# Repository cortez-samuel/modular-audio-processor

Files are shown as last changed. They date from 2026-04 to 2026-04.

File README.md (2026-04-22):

# Modular Audio Processor (Production Release)

## Overview
A real-time audio effects processor built on the Adafruit Feather RP2040. It processes I2S digital audio through various filters (Low-pass, High-pass, Gain, Quantize) and provides a live waveform/FFT visualization on an SSD1306 OLED display.

## Architecture
The system utilizes a multi-core architecture to ensure real-time audio processing performance.

- **Core 0 (Real-time Audio):**
    - Manages I2S Rx/Tx PIO state machines and DMA channels (`I2S.cpp`, `TxPingPong.cpp`).
    - Processes audio samples using floating-point filters (`filters.cpp`).
    - Maintains cyclic buffers for filter history (`CyclicBuffer_t`).
- **Core 1 (UI & Control):**
    - Renders the OLED display (`oled.cpp`), switching between Waveform and FFT views.
    - Handles user input via rotary encoders and push buttons (`RotaryEncoder.hpp`, `PushButton.hpp`).
    - Manages non-volatile storage of settings in flash memory.
- **Inter-Core Communication:**
    - A FIFO queue (`sharedQueue`) passes downsampled audio data from Core 0 to Core 1 for visualization without locking.

## Features
- **Audio Effects:**
    - **SRC:** Pass-through
    - **LPF/HPF:** First-order IIR filters with adjustable cutoff (`alpha`)
    - **GAIN:** Quadratic gain scaling
    - **QTZ:** Bit-crusher/Quantizer effect
- **Visualization:**
    - Real-time Oscilloscope
    - Real-time FFT Spectrum Visualizer (256 bins)
- **Persistence:** Saves current Mode and Alpha value to flash memory. It automatically restores on next power-up.

## Hardware Components
- Microcontroller: Adafruit Feather RP2040
- Display: SSD1306 OLED (128x64)
- Audio Codec: PCM5102 DAC Decoder Module and Mini Loudspeaker (3 Watt, 4 Ohm)
- Input: 2x CYT1100 Rotary Encoders with Push Switch

## Pinout
| Component | Pin Function | GPIO Pin |
|---|---|---|
| **OLED Display**| SCK | 10 |
| | MOSI (TX) | 11 |
| | RST | 28 |
| | DC | 29 |
| | CS | 24 |
| **I2S Audio** | Tx Data | 0 |
| | Tx BCLK | 2 |
| | Tx WS (LRCLK)| 3 |
| | Rx Data | 7 |
| | Rx BCLK | 8 |
| | Rx WS (LRCLK)| 9 |
| **Controls** | Mode Enc A | 12 |
| | Mode Enc B | 13 |
| | Mode SW | 25 |
| | Alpha Enc A  | 1 |
| | Alpha Enc B  | 6 |
| | Alpha SW | 20 |

## Build Instructions
1. Install the Raspberry Pi Pico SDK
2. Clone this repository
3. Create a `build` directory: `mkdir build && cd build`
4. Run CMake: `cmake ..`
5. Compile: `make`
6. Flash the `.uf2` file to the RP2040

## Usage
- **Mode Selection:** Turn the *Left* encoder to cycle between effects (SRC, LPF, HPF, GAIN, QTZ, FFT). Press the *Left* encoder button to reset to SRC mode.
- **Parameter Adjustment:** Turn the *Right* encoder to adjust the filter parameter (`alpha`). Press the *Right* encoder button to reset the parameter to `1.00` (or max).
- **Visualization:** The display will automatically show the waveform or FFT based on the selected mode.
- **Saving:** Settings are saved automatically after the last change.

## Known Bugs
- When continuously changing the alpha value when there is an incoming signal, both the display and audio output pause very briefly. This is because saving the flash memory operates within an ISR, which briefly stops the rest of the program to complete the flash write. We were not able to implement a solution to this as the ISR is needed to prevent reading and writing at the same time, which caused the system to crash during testing.

---

# Modular Audio Processor (Release Candidate)

## Overview
In the Release Candidate version of the Modular Audio Processor, the system consists of a dedicated input and one or more functions that connect via POGO pins. The system supports real-time DSP filtering and live FFT visualization, with all settings capable of being stored in flash memory. The Release Candidate represents a mostly polished build, as all planned features are integrated, the casings are complete, and usability has been refined based on feedback from our beta testing phase.

## Completed Work

### Hardware and Physical Design
- Designed and constructed dedicated input and function module casings (3D-printed and assembled).
- Input Module now uses a 3.5mm headphone jack for analog audio input instead of the DAD board's Waveform Generator.
- Function Modules output processed audio through a dedicated DAC with a 3.5mm headphone jack.
- System power is supplied using a USB-C breakout board (no direct connection to RP2040 USB-C port).
- User controls now use a rotary encoder instead of a potentiometer for intuitive control. Turning it adjusts the filter parameter alpha and pressing it changes the current DSP mode.
- Another button was added to allow the user to save these settings to flash memory, allowing the configuration to persist even after the system loses power.

### Intermodular Communication
- Full I2S-based communication using the RP2040 PIO for stereo-aligned, low-latency audio at 44.1 kHz
- We're still using dual-core optimization, with Core 0 handling the real-time audio pipeline (I2S RX -> DSP -> I2S TX) and Core 1 handling the OLED display logic.
- Added clock-forward PIO program to maintain clean BCLK/WS synchronization across chained modules.

### DSP Features
- The system now uses fixed-point arithmetic throughout for low latency and highly precise processing.
- Downsampled waveform/FFT data streamed to the display without impacting audio performance.

## Project Architecture

### Module Types
- **Input Module**: Reads analog audio from the 3.5mm headphone jack via the RP2040 ADC, performs fixed-point conversion, and transmits stereo I2S audio at 44.1 kHz frequency over POGO pins.
- **Function Module**: Receives I2S audio via POGO pins, applies the selected filter or FFT, and forwards the processed audio via I2S TX. It also handles user input (rotary encoder + mode button), flash persistence, and OLED display.

### Core Allocation
- **Core 0** (audio/DSP): I2S RX -> selectable filter or FFT -> I2S Tx. Uses DMA ping-pong buffers for zero-copy, real-time operation. It includes downsampling for display data.
- **Core 1** (OLED Display): Drives the 128 by 64 SSD1306 OLED display, renders either a live oscilloscope-style waveform display or FFT bar graph, and displays current mode and alpha value.

### State & Persistence
- Mode and alpha are stored in the last flash sector using a magic-byte header.
- `loadMode()` and `saveMode()` run at boot and on every user change.
- Flash writes are performed safely with `flash_safe_execute` to avoid XIP conflicts.

### Inter-Module Communication
- I2S bus (BCLK, WS, SD) carried over POGO pins.
- Dedicated PIO program forwards the clock signals to maintain synchronization in long chains.
- Power and ground are also passed through the POGO connectors.

## Known Bugs
- If the user partially disconnects the modules in such a manner that the POGO pins transmitting the I2S signals are detached but VCC and GND are stil connected, once the user fully reconnects the modules, it messes up the audio signal. This is caused by the PIO using autopull. However, this would be something that the user would need to delibrately do and isn't an issue that would usually come up in normal use.
- There are rare DMA underflow events that print a debug message to UART during extreme buffer starvation (though this is never audible in normal use and is automatically recovered by inserting default data).
- In this version, there are no major bugs, crashes, or loss of functionality. The edge cases (power-cycle, rapidly changing modes, alpha = 0, and buffer overflow/underflow) are handled properly.

---

# Modular Audio Processor (Beta Build)

## Completed Work
During the beta building phase, we primarily focused on transitioning from our breadboard prototype to a robust, integrated hardware system and improving the intermodular communication.

### Hardware and Physical Design
- Designed and implemented the first iteration of 3D-printed casings and moved away from prototyping breadboards.
- Replaced breadboard wiring with magnetic pogo pins for connection between modules
- Most internal components have been successfully fitted into their respective module casings.

### Firmware and Intermodular Communication
- Switched from SPI to I2S protocol using the RP2040's PIO to ensure stereo alignment and better audio quality.
- Switched from Arduino to the C++ SDK for coding to have better control over precision timing.
- Modules now have a persistent state in which they store the most recent filter settings and parameters in memory and retaining them even after being disconnected.
- Implemented a dual-core optimization strategy in which Core 0 handles I2S and DSP operations and Core 1 handles the UI and OLED display to prevent high latency.

### DSP Features
- Implemented special effect modes (Reverb, Gain, and Distortion) with adjustable parameters.

## Project Architecture

### Core Allocation
- The system is built on the Adafruit Feather RP2040 dual-core architecture.
- Core 0 is responsible for starting I2S DMA, reading 16-bit samples, applying DSP math (filtering/effects), and writing the output to the I2S bus.
- Core 1 is responsible for managing the user interface, including reading the adjustable knob value, plotting the waveforms/FFT, and refreshing the OLED display.

### State Logic
- The modules operate on a state-machine logic.
1. Upon powering up, the module searches for a Word Select and Bit Clock signal for syncing.
2. Once a clock match is found, the module enters a processing loop (Read -> Process -> Write)
3. If a signal is lost, the system enters an error state or returns to syncing until a connection is restored.

## Known Bugs and Limitations
- There are occassional connectivity issues with the pogo pins. They sometimes require manual adjustment to maintain a signal.
- The physical housing for user controls (knobs/buttons) have not yet been robustly designed.
- Dedicated input and output modules have not yet been implemented. Currently, power and analog signals are supplied via manual wiring.
- While the 3D-printed casing is structurally secure, the internal components require further mounting to prevent movement inside the casing.

---

# Modular Audio Processor (Alpha Build)

## Architecture

Mostly follows the prototype build:

- Targets Adafruit Feather RP2040
- Application state stored to FLASH
- SSD1306 display still in-use
- Difference from prototype: switch from SPI to I2S for intermodular communication
- Difference from prototype: ADC input/DAC output in process of being separated

## Completed Work

- Persistent state by storing filter parameter(s)
- External interface via display to user & interactable buttons/knobs
- Internal systems (filtering)

## Bugs & Incompleteness

- Intermodular communication is currently incomplete due to migration to I2C
- No 3d printed casing model so far

---

# Modular Audio Processor (Prototype Build)

The prototype build targets the Adafruit Feather RP2040 (8MB external QSPI flash) and focuses on real-world hardware integration with persistent storage and safe concurrent ADC operation during flash programming.

## Completed Work

### Persistent Storage (Flash-backed):

- Implemented a single-sector, page-aligned flash storage module.
- Stores application state (effect type, alpha parameter, write counter) in external QSPI flash at a safe offset (4MB).
- Uses a write counter to track saves and detect stale data on startup.
- At initialization (`persistent_init()`), the module reads the stored record from flash via XIP (execute-in-place) and stores to an in-memory cache.
- On save (`persistent_save()`), the new state is written to flash with automatic counter increment and post-write verification.

### OLED Display

The display utilizes custom drivers to interface with the SSD1306 display over SPI. The pins are pre-configured to use the top-left most pins on the Feather RP2040.

### ADC Signal Input

The ADC initializes pins A0-A3 as ADC channels.
- Allows for enabling/disabling the of ADC, alog with configuration.
- Reads from the active ADC channel, and updates that channel to show it has new data.
- Allows for interrupts, which helps with consistend sampling rates if desired.
- Lets the ADC read once or run at a consistend sampling rate, writing to the ADC FIFO.

## Known Bugs and Issues

- Wanted to implement round robin wear spreading for the persistent memory to limit how much each section of flash is written to. However, to do this we would have had to use four 4096-byte sectors for only a small persistent state memory. This would have been too much memory for so little, so had to be abandoned for now.
- ADC interrupts may interfere with peristent storage.

## Building

- Download the Pico-SDK and ensure the environment variable `PICO_SDK_PATH` on your system is set to it's location.
- Ensure the `arm-none-eabi` compile toolchain is installed.
- From root, run:
```
mkdir build
cd build
cmake ..
make
```
- This should create the .uf2 file in `/build` to install on the Feather RP2040

---

# Modular Audio Processor (Pre-Alpha Build)

For this pre-alpha build, we decided to use a Wokwi simulation of a Pi Pico (which also uses the RP2040 chip). This way, we can test the feasibility of our design before we invest resources into physically constructing a prototype. In summary, this pre-alpha build reads an analog signal from a potentiometer that simulates audio input, applies a configurable digital filter, and displays both the original and filtered waveforms on two separate OLED displays.

## Completed Work

Core Hardware Initialization: The major peripherals for this system are configured.
- ADC: Two channels (GP26 for signal, GP27 for filter control).
- GPIO: Two buttons (GP28 for *alpha* parameter adjustment, GP22 for save).
- SPI: spi0 is initialized and transmits the raw ADC signal.
- I2C: Two separate I2C buses (i2c0 and i2c1) are set up.

### Dual OLED Driver:

- A custom driver for the SH1107 OLED display is complete.
- It successfully manages two separate displays on two different I2C ports, each with its own framebuffer.

### Waveform Visualization:

- The draw_waveform function correctly renders a 128-sample circular buffer to the OLEDs, which creates a scrolling effect (similar to an oscilloscope).
- Display labels ("OG", "LPF") and simple borders are also drawn.

### Filter Implementation:

- A first-order IIR Low-Pass Filter is implemented.
- A High-Pass Filter is also implemented but not currently used.
- The main application uses a function pointer to select the active filter, which makes the system expandable.

### Dynamic Filter Control:

- The filter's *alpha* coefficient, which controls the cutoff frequency, can be adjusted in real-time.
- Holding button 1 reads ADC channel 1 and maps its value to an *alpha* between 0.05 and 0.95.

### Persistent State (Emulated):

- A module for saving and loading the *alpha* parameter is implemented.
- Pressing button 2 saves the current *alpha* value.
- The value is loaded on startup (this is currently an in-memory emulation and not an actual non-volatile flash storage).

### Error Detection Module (SignalErrorDetection.c):

- Functions for Checksum-8 and CRC-8 encoding and decoding have been written.
- Unit test functions (testChecksum8, testCRC8) are implemented and run at startup to verify the logic.

## Project Architecture

### Main Application (main.c)

1.  Initialization:
- Initializes the hardware peripherals (GPIO, SPI, ADC, I2C)
- Calls `persistent_init()` and `persistent_load()` in order to get the last saved *alpha* value.
- Initializes the two OLED displays
- Fills signal buffers with an initial ADC reading to prevent noise.
- Runs the `testChecksum8()` and `testCRC8()` self-tests.
- Sets the `cur_filter` function pointer to the low-pass filter configuration.
2. Main Loop:
- Uses input polling to check the state of the two buttons (*alpha* adjustment and save)
- *Alpha adjustment* (Button GP28): When pressed, it pauses the loop and `adc_read()` is called on channel 1 to update the *alpha* variable.
- Save (Button GP22): When pressed, the current *alpha* value is saved to the `PersistentState` struct and `persistent_save()` is called.
- During signal processing, the input signal (`og_signal`) is read from ADC channel 0. The input signal is transmitted via SPI. Then, the signal is stored in the `input_buffer`. Then, the `cur_filter` function, which points to the `low_pass` configuration, is called to calculate the filtered sample. This result is stored in the `filter_buffer` and the circular buffer index is incremented.
- During rendering, `oled_fill` clears both the OLED framebuffers. The `input_buffer` is drawn to OLED display 0 (OG) and the `filter_buffer` is drawn to OLED display 1 (LPF). Both of these framebuffers are pushed to the displays using `oled_update`.
- A delay, `sleep_ms(50)` is added to configure the sample and refresh rate of the main loop.

### Core Modules

- `oled.h` and `oled.c`: Manages both the SH1107 OLED displays. It takes an ID number, 1 or 0, to choose the appropriate I2C bus and corresponding framebuffer for all the drawing operations.
- `filters.h` and `filters.c`: Contains the mathematical logic for the digital filters. They operate on the original and filtered signal buffers in order to compute the next outputsample.
- `persistent_state.h` and `persistent_state.c`: This module emulates non-volatile storage. The `static PersistentState` variable holds the saved data. When we begin constructing a physical prototype of our project, this module will be responsible for writing to the flash memory.
- `SignalErrorDetection.h` and `SignalErrorDetection.c`: This is a utility module for data integrity checks. It is not being used by the main signal processing loop.

## Known Bugs and Issues

- Our `high_pass` filter implementation has a weird behavior and is not working as expected. Even though our current implementation is based on a standard discrete-time transfer function, it is not performing a true high-pass filter on the input signal and needs further investigation.
- The button used for the save state doesn't have any debouncing logic. This also applies to the *alpha* adjustment button and the "next filter" button; holding down the latter could cause the system to swap between filters repeatedly instead of registering it as a single press.
- There is an issue with our display in that a waveform wraps around (this means that after a waveform shape leaves from the left side, it comes back to the right side).
- Right now, the `persistent_state` module does not save to flash mmory, as any saved `alpha` value is lost when the Wokwi simulation is reset. However, this can be implemented properly when we use the Pico's SDK flash memory API during the physical construction of our prototype.
- Since Wokwi only allows one MCU in a simulation, we were not able to formally verify the functionality of receiving data via SPI. While the RP2040 does have two SPI buses, using both of them to test transmission and receiving caused blocking, which created a lot of lag in the Wokwi simulation. Thus, we could not simulate the daisy-chained SPI communication between modules. However, we were able to verify the functionality of the SPI transmission using a logic analyzer to observe the SCK, CS, and TX signals. Thus, we do not have reason to believe that another RP2040 would have difficulties receiving the data via SPI.

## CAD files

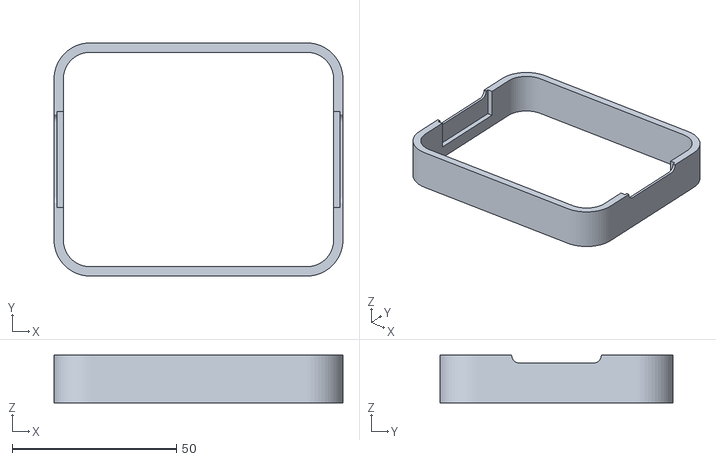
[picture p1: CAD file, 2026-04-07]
stl/Function Module/MAP - Half Trim New.stl
88.0 x 71.0 x 14.5

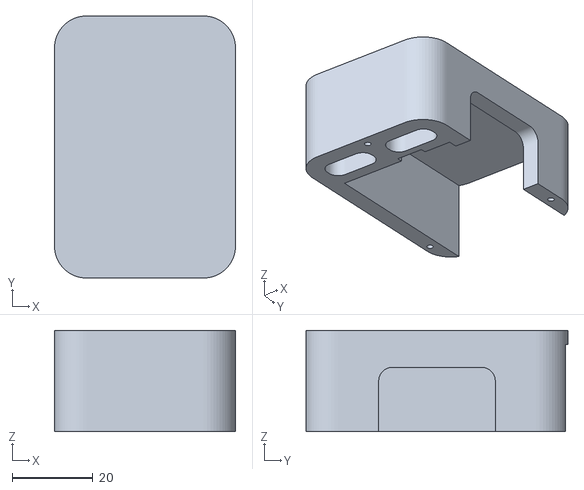
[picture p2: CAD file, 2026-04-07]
stl/Input Module/MAP - Input body.stl
44.7 x 64.7 x 25.0

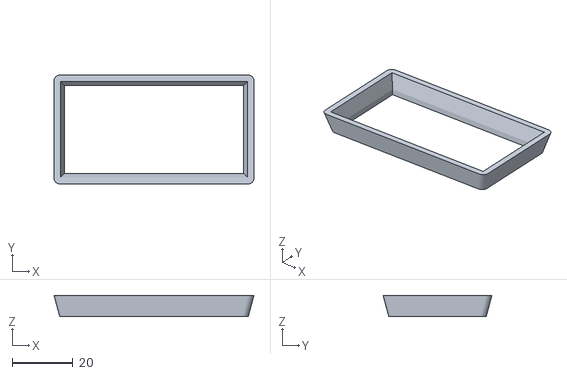
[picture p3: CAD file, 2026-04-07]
stl/Function Module/MAP - Inlay.stl
65.8 x 35.8 x 7.00

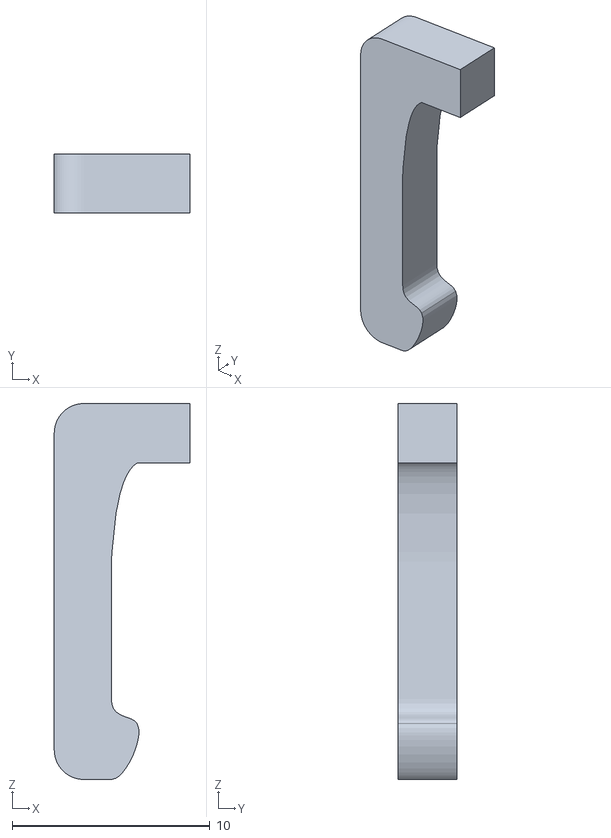
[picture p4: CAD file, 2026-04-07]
stl/Input Module/MAP - Input wire clip.stl
6.85 x 3.00 x 19.0

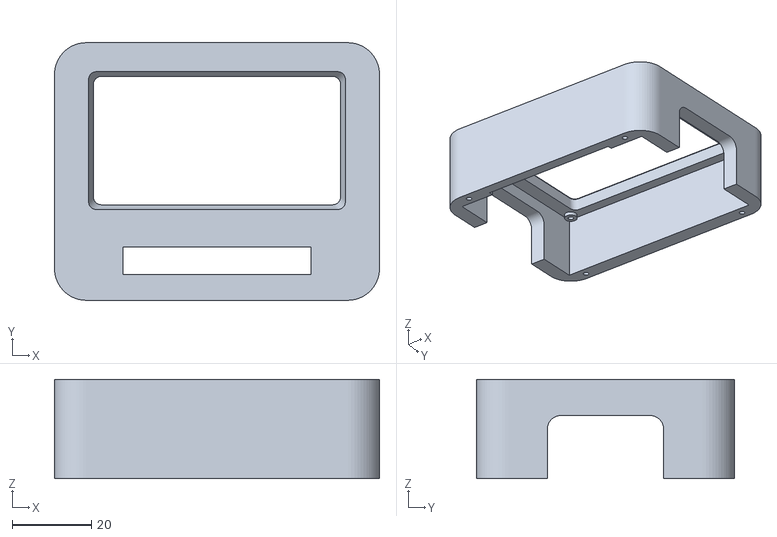
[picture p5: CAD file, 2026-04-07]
stl/Function Module/MAP - Body.stl
82.0 x 65.0 x 25.0

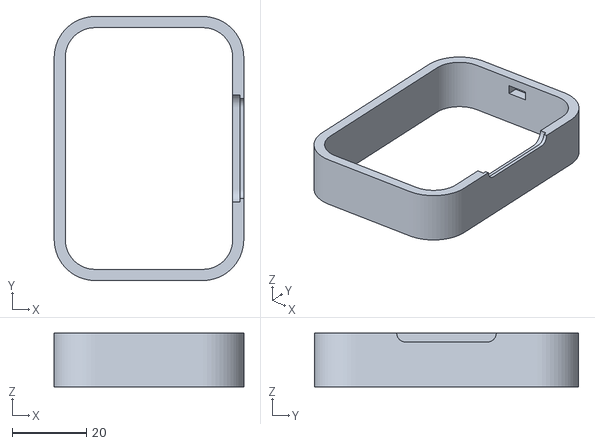
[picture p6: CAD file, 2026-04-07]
stl/Input Module/MAP - Input trim 2.stl
51.0 x 71.0 x 14.5

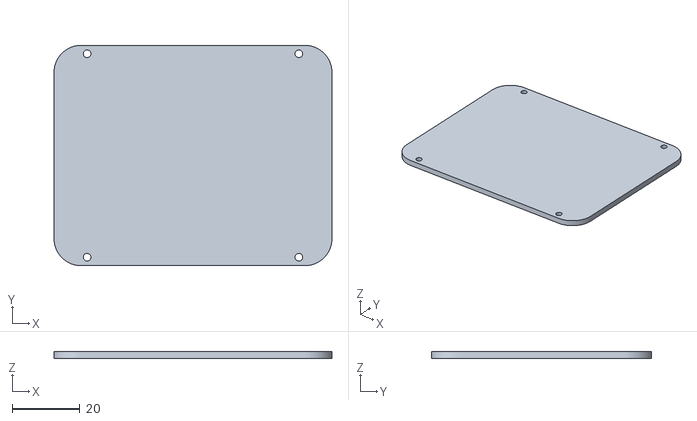
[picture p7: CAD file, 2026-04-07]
stl/Function Module/MAP - Back lid.stl
82.0 x 65.0 x 2.00

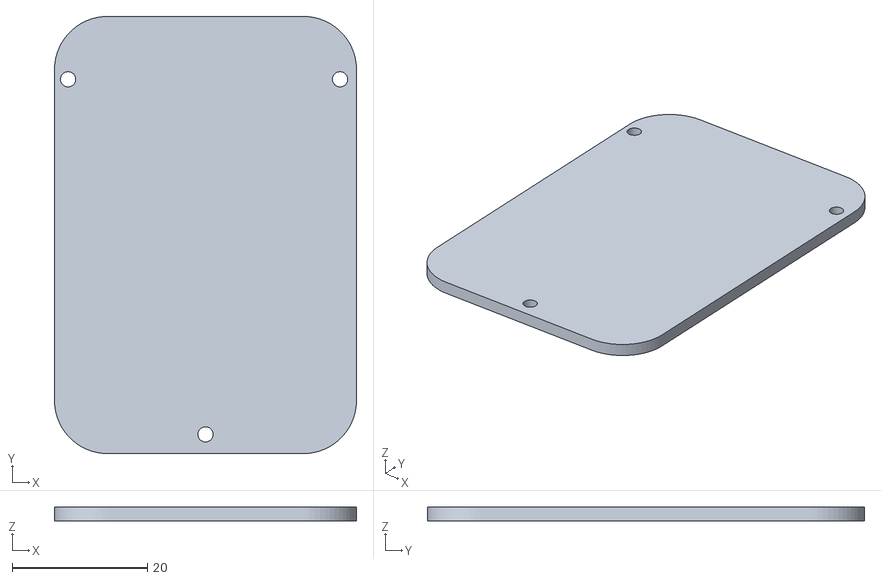
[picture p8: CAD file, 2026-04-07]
stl/Input Module/MAP - Input lid.stl
44.7 x 64.7 x 2.00

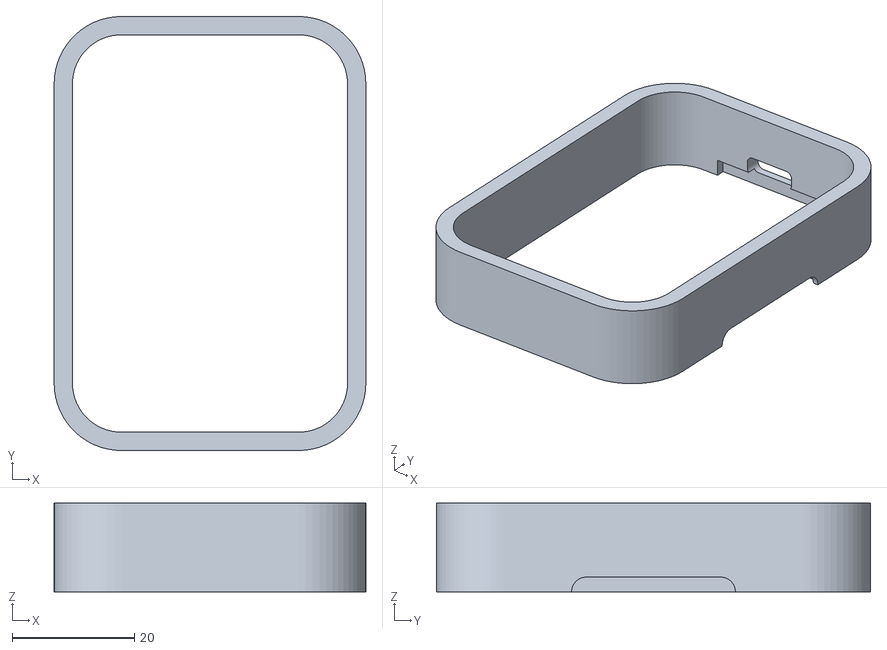
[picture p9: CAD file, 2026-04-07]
stl/Input Module/MAP - Input trim 1.stl
51.0 x 71.0 x 14.5

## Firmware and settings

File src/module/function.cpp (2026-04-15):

#include "pico/stdlib.h"
#include "hardware/pio.h"
#include "hardware/dma.h"
#include "hardware/irq.h"
#include "hardware/flash.h"
#include "hardware/sync.h"
#include "pico/flash.h"
#include "pico/multicore.h"
#include "pico/util/queue.h"
#include "../lib/I2S.h"
#include "../lib/oled.h"
#include "../lib/adc.hpp"
#include "../lib/fft.hpp"
#include "../lib/PushButton.hpp"
#include "../lib/RotaryEncoder.hpp"
#include "../lib/filters.h"
#include "../lib/mode.h"

    // LED PIN
static const uint LED_PIN           = 13;
static volatile uint LED_PIN_VALUE  = 0;

    // OLED
static const auto    SPI_INSTANCE   = spi1;
static const uint8_t PIN_SCK        = 10;
static const uint8_t PIN_TX         = 11;
static const uint8_t PIN_RST        = 28;
static const uint8_t PIN_DC         = 29;
static const uint8_t PIN_CS         = 24;

    // SHARED STUFF
static volatile uint8_t DOWNSAMPLE_FACTOR   = 16;
static const uint8_t    SHARED_BUFFER_WIDTH = 64;
static const uint8_t    SHARED_BUFFER_DEPTH = 128;
static queue_t sharedQueue;

    // I2S Tx
static const uint8_t PIN_I2S_Tx_SD   = 0;
static const uint8_t PIN_I2S_Tx_BCLK = 2;
static const uint8_t PIN_I2S_Tx_WS   = 3;
static I2S_Tx i2sTx;
static const uint32_t Tx_reservedMemDepth = 128;
static const uint32_t Tx_reservedMemWidth = 8;
static uint32_t Tx_reservedMem[Tx_reservedMemDepth * Tx_reservedMemWidth];
static uint32_t Tx_defaultMem[Tx_reservedMemDepth];

    // I2S Rx
static const uint8_t PIN_I2S_Rx_SD   = 7;
static const uint8_t PIN_I2S_Rx_BCLK = 8;
static const uint8_t PIN_I2S_Rx_WS   = 9;
static I2S_Rx i2sRx;
static const uint32_t Rx_reservedMemDepth = 128;
static uint32_t Rx_reservedMem[Rx_reservedMemDepth * RxPingPong::WIDTH];

    // I2S GENERAL
static const uint  I2S_WS_FRAME_WIDTH = 16;
static const float fs                 = 44100;

    // FILTERS
static float volatile alpha          = 1.0f;
static float alphaMin                = 0.0f;
static float alphaMax                = 1.0f;
static const uint FILTER_BUFFER_DEPTH   = 128;
static float buffer_X[FILTER_BUFFER_DEPTH];
static float buffer_Y[FILTER_BUFFER_DEPTH];
static CyclicBuffer_t<float> cyclicBuffer_X(buffer_X, FILTER_BUFFER_DEPTH);
static CyclicBuffer_t<float> cyclicBuffer_Y(buffer_Y, FILTER_BUFFER_DEPTH);

static Mode g_mode = Mode::Pass;      // default: SRC / Pass
#define MODE_DEF(m) (MODES[mode_to_u32(m)])

static const uint64_t PUSH_BUTTON_DEBOUNCE_TIME_us  = 50000;

    // MODE ROTARY ENCODER  — turning cycles mode, pressing resets to SRC
static const uint8_t  PIN_MODE_ENCODER_A             = 12;
static const uint8_t  PIN_MODE_ENCODER_B             = 13;
static const uint8_t  PIN_MODE_ENCODER_SW            = 25;

    // ALPHA ROTARY ENCODER — turning adjusts alpha, pressing resets to 1.00
static const uint8_t  PIN_ALPHA_ENCODER_A            = 1;
static const uint8_t  PIN_ALPHA_ENCODER_B            = 6;
static const uint8_t  PIN_ALPHA_ENCODER_SW           = 20;

static const uint64_t ROTARY_ENCODER_DEBOUNCE_TIME_us   = 10000;
static const uint8_t  ROTARY_ENCODER_MIN_POSITION       = 0;
static const uint8_t  ROTARY_ENCODER_MAX_POSITION       = 100;

    // flags set inside ISR, consumed by core1 main loop
static volatile bool pendingModeChange  = false;    // advance mode (positive turn)
static volatile bool pendingModeReverse = false;    // retreat mode (negative turn)
static volatile bool pendingModeReset   = false;    // reset mode to SRC (SW press)
static volatile bool pendingAlphaReset  = false;    // reset alpha to 1.00 (SW press)
static volatile bool pendingFlashSave   = false;
static volatile bool flashSaveDone      = false;
static volatile float    lastSavedAlpha = -1.0f;   // sentinel: forces first save
static volatile uint32_t lastSavedMode  = 0xFFFFFFFFu;

#define FEATHER_RP2040_FLASH_SIZE   (8u * 1024u * 1024u)   // 8 MB
#define FLASH_MAGIC         0xA55A1234u
#define FLASH_TARGET_OFFSET (FEATHER_RP2040_FLASH_SIZE - FLASH_SECTOR_SIZE)

struct FlashData {
    uint32_t magic;
    float alpha;
    uint32_t mode;      // stored as uint32_t so the struct layout stays simple
};

static void __not_in_flash_func(flashWriteCallback)(void* param) {
    const FlashData* d = reinterpret_cast<const FlashData*>(param);
    static uint8_t pageBuf[FLASH_PAGE_SIZE];
    __builtin_memset(pageBuf, 0xFF, sizeof(pageBuf));
    __builtin_memcpy(pageBuf, d, sizeof(FlashData));
    flash_range_erase(FLASH_TARGET_OFFSET, FLASH_SECTOR_SIZE);
    flash_range_program(FLASH_TARGET_OFFSET, pageBuf, FLASH_PAGE_SIZE);
}

// save current alpha and mode to flash
static void saveToFlash(float a, Mode m) {
    static FlashData data;          // static so it stays alive inside the callback
    data.magic = FLASH_MAGIC;
    data.alpha = a;
    data.mode  = mode_to_u32(m);
    // flash_safe_execute pauses the other core so both aren't executing from flash
    flash_safe_execute(flashWriteCallback, &data, UINT32_MAX);
}

// try to read previously saved data, returns true on success.
static bool loadFromFlash(float& outAlpha, Mode& outMode) {
    const FlashData* d = reinterpret_cast<const FlashData*>(
        XIP_BASE + FLASH_TARGET_OFFSET);
    if (d->magic != FLASH_MAGIC) return false;
    outAlpha = d->alpha;
    outMode  = static_cast<Mode>(d->mode);
    return true;
}

static const float _E_SCALE = 32768.0f;
static inline float fix_to_float(int16_t x) {
    return static_cast<float>(x) / _E_SCALE;
}
static inline int16_t float_to_fix(float x) {
    if (x >=  1.0f) return  0x7FFF;
    if (x <= -1.0f) return static_cast<int16_t>(0x8000);
    return static_cast<int16_t>(x * 32767.0f);
}
static inline float clamp_f(float lo, float x, float hi) {
    return x < lo ? lo : (x > hi ? hi : x);
}

//  CALLBACKS

// Mode encoder — positive turn: advance mode
static void modeEncPosCallback(
    RotaryEncoder<ROTARY_ENCODER_DEBOUNCE_TIME_us>* /*enc*/,
    RotaryEncoder<ROTARY_ENCODER_DEBOUNCE_TIME_us>::State_t /*next*/)
{
    pendingModeChange = true;
}

// Mode encoder — negative turn: retreat mode
static void modeEncNegCallback(
    RotaryEncoder<ROTARY_ENCODER_DEBOUNCE_TIME_us>* /*enc*/,
    RotaryEncoder<ROTARY_ENCODER_DEBOUNCE_TIME_us>::State_t /*next*/)
{
    pendingModeReverse = true;
}

// Mode encoder switch — press: reset mode to SRC
static void modeEncSwUpCallback(
    PushButton<PUSH_BUTTON_DEBOUNCE_TIME_us>* /*pb*/,
    PushButton<PUSH_BUTTON_DEBOUNCE_TIME_us>::State_t /*next*/)
{
    pendingModeReset = true;
}

// Alpha encoder switch — press: reset alpha to 1.00
static void alphaEncSwUpCallback(
    PushButton<PUSH_BUTTON_DEBOUNCE_TIME_us>* /*pb*/,
    PushButton<PUSH_BUTTON_DEBOUNCE_TIME_us>::State_t /*next*/)
{
    pendingAlphaReset = true;
}

// CORE 1 – OLED DISPLAY + INPUT HANDLING
void core1_entry() {
    flash_safe_execute_core_init();
    multicore_fifo_push_blocking(0);

    // Initialize OLED
    gpio_set_function(PIN_SCK, GPIO_FUNC_SPI);
    gpio_set_function(PIN_TX,  GPIO_FUNC_SPI);
    OLED oled(SPI_INSTANCE, PIN_CS, PIN_DC, PIN_RST, 128, 64);
    sleep_ms(500);
    if (!oled.begin(10 * 1000 * 1000)) {
        while (true) {
            gpio_put(LED_PIN, 1); sleep_ms(500);
            gpio_put(LED_PIN, 0); sleep_ms(500);
        }
    }

    // Startup splash
    oled.clearDisplay();
    oled.setCursor(10, 5);
    oled.setTextSize(2);
    oled.setTextColor(true);
    oled.print("Modular \n Audio \n Processor");
    oled.display();
    sleep_ms(2000);

    // load saved state from flash
    {
        float   savedAlpha = 1.0f;          // default: 1.00
        Mode    savedMode  = Mode::Pass;    // default: SRC

        if (loadFromFlash(savedAlpha, savedMode)) {
            savedAlpha = clamp_f(alphaMin, savedAlpha, alphaMax);
        }

        alpha = savedAlpha;
        g_mode  = savedMode;
    }

    GPIO_IRQManager::init();

    // Mode rotary encoder — turning cycles mode forward/backward
    RotaryEncoder<ROTARY_ENCODER_DEBOUNCE_TIME_us> modeRotaryEncoder;
    modeRotaryEncoder.setCallback(modeEncPosCallback, false, true);  // positive turn
    modeRotaryEncoder.setCallback(modeEncNegCallback, true,  true);  // negative turn
    modeRotaryEncoder.begin(PIN_MODE_ENCODER_A, PIN_MODE_ENCODER_B);

    // Mode encoder switch — press resets mode to SRC
    PushButton<PUSH_BUTTON_DEBOUNCE_TIME_us> modeEncSwPushButton;
    modeEncSwPushButton.setCallback(modeEncSwUpCallback, true, true);   // onUp
    modeEncSwPushButton.begin(PIN_MODE_ENCODER_SW);

    // Alpha rotary encoder — turning adjusts alpha value
    RotaryEncoder<ROTARY_ENCODER_DEBOUNCE_TIME_us> alphaRotaryEncoder;
    alphaRotaryEncoder.begin(PIN_ALPHA_ENCODER_A, PIN_ALPHA_ENCODER_B);
    alphaRotaryEncoder.setState(static_cast<int>(alpha * 100.0f + 0.5f));

    // Alpha encoder switch — press resets alpha to 1.00
    PushButton<PUSH_BUTTON_DEBOUNCE_TIME_us> alphaEncSwPushButton;
    alphaEncSwPushButton.setCallback(alphaEncSwUpCallback, true, true); // onUp
    alphaEncSwPushButton.begin(PIN_ALPHA_ENCODER_SW);

    // Waveform circular buffer
    static const int CIRCULAR_BUFFER_SIZE = 512;
    uint32_t circularBuffer[CIRCULAR_BUFFER_SIZE] = {0};
    int      bufferWriteIndex = 0;
    uint32_t lastDisplayTime  = 0;
    const uint32_t DISPLAY_INTERVAL_MS = 33;
    static uint32_t lastAutoSaveCheck_ms = 0;

    while(true){
        // service deferred ISR flags
        uint32_t now = time_us_32() / 1000;

        if (pendingModeChange) {
            pendingModeChange = false;
            g_mode = mode_cycle(g_mode);
        }
        if (pendingModeReverse) {
            pendingModeReverse = false;
            g_mode = mode_cycle_rev(g_mode);
        }
        if (pendingModeReset) {
            pendingModeReset = false;
            g_mode = mode_default();
        }
        if (pendingAlphaReset) {
            pendingAlphaReset = false;
            alpha = 1.0f;
            alphaRotaryEncoder.setState(100);   // 1.00 * 100
        }
        if (flashSaveDone) {
            flashSaveDone = false;
        }

        // PERIODIC AUTO-SAVE (every 2 seconds, only when state changed)
        if (now - lastAutoSaveCheck_ms >= 2000) {
            lastAutoSaveCheck_ms = now;
            float    curAlpha = alpha;
            uint32_t curMode  = static_cast<uint32_t>(g_mode);
            if (curAlpha != lastSavedAlpha || curMode != lastSavedMode) {
                lastSavedAlpha = curAlpha;
                lastSavedMode  = curMode;
                pendingFlashSave = true;
            }
        }

        // alpha encoder -> alpha value (clamped to [0.00, 1.00])
        int encPosition = alphaRotaryEncoder.getState();

        if (encPosition > ROTARY_ENCODER_MAX_POSITION) {
            encPosition = ROTARY_ENCODER_MAX_POSITION;
            alphaRotaryEncoder.setState(ROTARY_ENCODER_MAX_POSITION);
        }
        if (encPosition < ROTARY_ENCODER_MIN_POSITION) {
            encPosition = ROTARY_ENCODER_MIN_POSITION;
            alphaRotaryEncoder.setState(ROTARY_ENCODER_MIN_POSITION);
        }

        alpha = encPosition / 100.0f;

        // Drain inter-core queue
        uint32_t word;
        while (queue_try_remove(&sharedQueue, &word)) {
            circularBuffer[bufferWriteIndex] = word;
            bufferWriteIndex = (bufferWriteIndex + 1) % CIRCULAR_BUFFER_SIZE;
        }
        if (now - lastDisplayTime >= DISPLAY_INTERVAL_MS) {
            lastDisplayTime = now;
            oled.clearDisplay();
            if (g_mode == Mode::FFT) {
                fi16 fftIn[256];
                for (int i = 0; i < 256; i++) {
                    fftIn[i] = (fi16)(int16_t)(uint16_t)circularBuffer[i];
                }
                int32_t mean = 0;
                for (int i = 0; i < 256; i++) { mean += fftIn[i]; }
                mean >>= 8;
                for (int i = 0; i < 256; i++) { fftIn[i] -= (fi16)mean; }
                fi16_32 fftOut[256];
                fft_fixed(fftIn, fftOut);
                fi16_32 fftOut_max = 1;
                for (int i = 0; i < 128; i++) {
                    if (fftOut[i] > fftOut_max) fftOut_max = fftOut[i];
                }
                bool     max_gt_64k = fftOut_max > 65535;
                uint32_t scale      = max_gt_64k
                    ? (uint32_t)(fftOut_max / 65535 + 1)
                    : (uint32_t)(65535 / fftOut_max);
                for (int x = 0; x < 128; x++) {
                    uint16_t dp = (uint16_t)(max_gt_64k
                        ? (fftOut[x] / scale)
                        : (fftOut[x] * scale));
                    uint8_t y = 63 - (uint8_t)(dp >> 10);
                    for (int row = 63; row > (int)y; row--) {
                        oled.drawPixel(x, row, true);
                    }
                }
            }
            else {
                for (int x = 0; x < 128; x++) {
                    if (x % 4 < 2) oled.drawPixel(x, 32, true);
                }
                int lastY = 32;
                for (int x = 0; x < 128; x++) {
                    int bufIdx = (bufferWriteIndex + x * 4) % CIRCULAR_BUFFER_SIZE;
                    int16_t  s          = (int16_t)(uint16_t)circularBuffer[bufIdx];
                    uint16_t offset_bin = (uint16_t)s ^ 0x8000u;
                    uint8_t  y          = 63 - (uint8_t)(offset_bin >> 10);
                    if (y > 63) y = 63;
                    if (x > 0) {
                        int diff = (int)y - lastY;
                        if (diff > 0) {
                            for (int dy = lastY; dy <= (int)y; dy++)
                                oled.drawPixel(x, dy, true);
                        } else if (diff < 0) {
                            for (int dy = lastY; dy >= (int)y; dy--)
                                oled.drawPixel(x, dy, true);
                        }
                    }
                    oled.drawPixel(x, y, true);
                    lastY = y;
                }
            }
            oled.setTextSize(1);
            oled.setTextColor(true);
            oled.setCursor(0, 0);
            oled.print(MODE_DEF(g_mode).name);
            if (MODE_DEF(g_mode).filter != Filters::PASS) {
                char buf[12];
                snprintf(buf, sizeof(buf), "a=%.2f", (float)alpha);
                oled.setCursor(128 - 6 * 6, 0);
                oled.print(buf);
            }
            oled.display();
        }
        sleep_us(100);
    }
}

// CORE 0 – I/O + FILTER
int main() {
    stdio_init_all();

    // LED
    gpio_init(LED_PIN);
    gpio_set_dir(LED_PIN, GPIO_OUT);

    // Inter-core queue
    queue_init(&sharedQueue, sizeof(uint32_t), 256);

    multicore_launch_core1(core1_entry);
    multicore_fifo_pop_blocking();
    i2sTx.setReservedMem(Tx_reservedMem, Tx_defaultMem, Tx_reservedMemWidth, Tx_reservedMemDepth);
    i2sTx.init(PIN_I2S_Tx_BCLK, PIN_I2S_Tx_WS, PIN_I2S_Tx_SD, fs, I2S_WS_FRAME_WIDTH);
    i2sRx.setReservedMem(Rx_reservedMem, Rx_reservedMemDepth);
    i2sRx.init(PIN_I2S_Rx_BCLK, PIN_I2S_Rx_WS, PIN_I2S_Rx_SD, fs, I2S_WS_FRAME_WIDTH);
    i2sTx.enable(true);
    i2sRx.enable(true);

    // initialize filter + mode
    g_mode          = Mode::Pass;

    uint32_t downsampleCounter = 0;

    while(true){
        if(pendingFlashSave){
            pendingFlashSave = false;
            // stop pio state machines to remove DREQ
            i2sTx.pause();
            i2sRx.pause();
            float snapAlpha = alpha;
            Mode  snapMode  = g_mode;
            saveToFlash(snapAlpha, snapMode);
            // resume PIO
            i2sRx.resume();
            i2sTx.resume();
            flashSaveDone = true;
        }

        uint32_t rxBuf[Rx_reservedMemDepth];
        if(i2sRx.readBuffer(rxBuf)){
            bool queuedValid = true;
            for (uint i = 0; i < Rx_reservedMemDepth / 2; i++) {
                // Get stereo sample and mix to mono
                int16_t raw_sample_LC = (int16_t)(uint16_t)rxBuf[2 * i];
                int16_t raw_sample_RC = (int16_t)(uint16_t)rxBuf[2 * i + 1];
                int16_t raw_sample    = (raw_sample_LC >> 1) + (raw_sample_RC >> 1);

                // Apply active filter
                float s_vol        = fix_to_float(raw_sample);
                float filtered_vol = call_filter(g_mode, &cyclicBuffer_X, &cyclicBuffer_Y, s_vol, alpha);
                filtered_vol       = clamp_f(-1.0f, filtered_vol, 1.0f);
                int16_t out_sample = float_to_fix(filtered_vol);

                // Output
                uint32_t tx_word = (uint32_t)(uint16_t)out_sample;
                queuedValid = i2sTx.queue(tx_word, tx_word) & queuedValid;

                // Downsample for display
                downsampleCounter++;
                if (downsampleCounter >= DOWNSAMPLE_FACTOR) {
                    downsampleCounter = 0;
                    uint32_t q_word = (uint32_t)(uint16_t)out_sample;
                    queue_try_add(&sharedQueue, &q_word);
                }
            }
        }
    }
}

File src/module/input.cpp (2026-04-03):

#include "pico/stdlib.h"
#include "hardware/adc.h"
#include "../lib/adc.hpp"
#include "../lib/I2S.h"
#include <cstdio>
#include <cstdint>

    // ADC / AUDIO INPUT
static const uint8_t ADC_CHANNEL = 0;
static const uint8_t PIN_ADC_CHANNEL = ADC_GET_CHANNEL_PIN(ADC_CHANNEL);

    // I2S Tx
static const uint8_t PIN_I2S_Tx_SD = 0;
static const uint8_t PIN_I2S_Tx_BCLK = 2;
static const uint8_t PIN_I2S_Tx_WS = 3;
static const uint I2S_WS_FRAME_SIZE = 16;
static const float fs = 44100;

    // FIXED POINT
static const int _E = 15;
static const float _E_SCALE  = (float)(1 << _E);

static inline int16_t float_to_fix(float x) {
    if(x >=  1.0f){
        return  0x7FFF;
    }
    if(x <= -1.0f){
        return (int16_t)0x8000;
    }
    return (int16_t)(x * _E_SCALE);
}

static inline int16_t adc_raw_to_fix(uint16_t raw12) {
    float u_vol = raw12 * (3.3f / 4096.0f);
    float s_vol = (u_vol - 1.65f) / 1.65f;
    return float_to_fix(s_vol);
}

int main() {
    stdio_init_all();

        // ADC INIT
    ADC::init(fs, true, false, 1, defaultADCRIQHandler);
    ADC::enableChannel(ADC_CHANNEL, true);
    ADC::setActiveChannel(ADC_CHANNEL);
    ADC::enableIRQ(true);
    ADC& adc0 = ADC::getActiveChannel();

        // I2S_Tx INIT
    const uint Tx_reservedMemDepth = 128;
    const uint Tx_reservedMemWidth = 8;
    uint32_t Tx_reservedMem[Tx_reservedMemDepth * Tx_reservedMemWidth];
    uint32_t Tx_defaultMem[Tx_reservedMemDepth];
    I2S_Tx i2sTx(Tx_reservedMem, Tx_defaultMem, Tx_reservedMemWidth, Tx_reservedMemDepth);

    i2sTx.init(PIN_I2S_Tx_BCLK, PIN_I2S_Tx_WS, PIN_I2S_Tx_SD, fs, I2S_WS_FRAME_SIZE);

        // ENABLE
    ADC::run(true);
    i2sTx.enable(true);

    int16_t lastSample = 0;
    while (true) {
        if (adc0.newValue()) {
            lastSample = adc_raw_to_fix(adc0.rawValue());
            uint32_t word = (uint32_t)(uint16_t)lastSample;
            bool queued = false;
            while(!queued) { queued = i2sTx.queue(word, word); }
        }
    }
}

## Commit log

2025-10-26 wokwi, oled screen text using pico-sdk
2025-10-26 oled, need to implement spi instead
2025-10-26 implemented some basic components to test serial communication, unable to get SPI to work
2025-10-26 added error detection to wokwi (demonstrated within the print log because we cannot add multiple microprocessors in project)
2025-10-27 filter.{c,h} for filtering
2025-10-27 filters in main
2025-10-27 added spi transmission implementation with logic analyzer
2025-10-27 filter swapping
2025-10-27 use state for filter swapping
2025-10-27 time track
2025-11-07 OLED display drivers
2025-11-14 Got ADC working on separate test project, builsing adc class + implementations here, and reconfiging CMakeLists a bit so test-files fcan still be compiled but will not be unless 'selected'
2025-11-14 finally got CMakeLists.txt to work with vscode and CLI, gonna change adc stuff a bit to be more 'functional' style since so many methods end up being on every adc channel, and you would just need to 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
2025-11-14 updated ADC and checked (in separate project) if read() will also activate a FIFO_IRQ (it can since data is placed into FIFO, does not seem to be popped off FIFO on its own either)
2025-11-14 got ADC struct working in project -- gonna need to add docs since initialization can be easy to forget something
2025-11-14 added spi test
2025-11-15 fixed pin numbers
2025-11-16 made a small R2R DAC 8-bit resolution in case we need it
2025-11-16 Pause ADC during flash writes and re-enable after completion
2025-11-17 update readme for ADC
2025-11-17 update readme for ADC -- forgot a #
2026-01-17 Added new timetracking file for new sem. Made a folder for it too incase we need to add images or smth. Researched I2S, rp2040 PIO, and made a plan for a I2S PIO in libraries/PIO/ currently plan is a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
2026-01-17 Got I2S_naive.pio program working along with init, and mono/stereo write functions. Have idea for an improved I2S program to ensure data stays synched with the correct channel. Will draft plan. Curre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
2026-01-18 Made another I2S transfer file, need to work on read. This is a plan for a channel-data secure (makes sure channel data is written with correct WS / on the correct channel), but limits databits per c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
2026-01-20 Made a working I2S Rx PIO script, needs the bclk, ws, sd pins in order. Does not make sure data is syched with WS while running, does this during setup and the sm needs to be reset to realign if it g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
    [I2S_Rx_test.cpp, I2S_Tx_test.cpp, adc_test.cpp]
2026-01-25 Finished with current I2S stuff. Added working SPI_Byte things, did not test regular SPI implementation though, but don't plan to use that, moreso inluded as a 'plan' and basic start for SPI_Byte
2026-01-30 added FFT test file (Arduino)
2026-01-30 Added DMA to I2S_Tx. Just need ot make sure the program uploaded matches the init, may add definition for that. May also add definitions to make variable buffer size. Need to do DMA for I2S_Rx too
2026-02-03 Added DMA to I2S Tx and Rx
2026-02-08 Working on pingpong DMA and pingpong Buffer for I2S_Rx and I2S_Tx respectively. Might be needed for faster Rx, probably not for faster Tx but can be included/worked on for consistency in functionality
2026-02-09 Got DMA ping-pong working in RX Test file, need to move to its own file. Some weird (I believe) alignment bug is happening keeping me from storing both channels and running/overflow flags at the same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
    [I2S_Rx_test.cpp, I2S_Tx_test.cpp]
2026-02-12 Got RxPingPong to work as own class. Needs a reserved memory space to be given to it, but allowing for variable buffer depth. Has sampled up to 100kHz consistently, have not tested above that speed.
2026-02-20 fixed issue where random waveform plotted waveform points would have a value of zero
    [module_INPUT.cpp]
2026-02-20 added UI for switching between filter modes
2026-02-27 fixed bug with HPF waveform and fixed audio output
    [module_INPUT.cpp]
2026-03-10 fixed overflow of Tx buffer in FUNCTION module by averaging LC and RC i2sRx inputs then queuing to both Tx channels. Can be changed to filter on LC and RC channnels separately with improved filter lo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
2026-03-11 fixed issue with I2S RX PIO not syncing WS frames every cycle
2026-03-15 added autoreframe PIO for I2S RX. will still read faulty data when disconnected, but only for a couple audio samples.
2026-03-23 got rotary encoder working. need to pretty up
2026-03-23 added push-button class. reformatted RotaryEncoder class to be in own file
2026-03-27 Implemented PUSHBUTTON + ENCODER in src file
2026-04-01 push-button fix
2026-04-06 added convenience things for filters
2026-04-07 STLs, function module
    [MAP - Back lid.stl, MAP - Body.stl, MAP - Half Trim New.stl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]
2026-04-07 STLs, input module
    [MAP - Input body.stl, MAP - Input lid.stl, MAP - Input trim 1.stl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]
2026-04-10 fixed crashing w/ incoming i2s data
    [function.cpp]
2026-04-15 refactor filters/mode
2026-04-16 gain filter
